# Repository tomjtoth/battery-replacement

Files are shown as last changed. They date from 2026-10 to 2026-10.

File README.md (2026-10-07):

# 3.9V battery replacement

I'd like to replace Li-ion cells from the battery package of mobile devices
with this DC DC converter, which shall step 5V received from any USB port/charger down to 3.9V.

## Conflict with charging via USB port

The devices USB port should not be used for charging after this integration.
Special cables (with unconnected VBUS) should be used when connecting to computers.

## Design choices

At 5V3A - a type-C DFP can provide without active negotiation - the _ideal_ power budget is 15W.
That should translate to about 3.84A at 3.9V.

As a worst case scenario I picked the largest transient as 3.8A and V_IN as 4.5V.
Using the converter's formulas I got 272.6mV sag and 12.7mV soar on the output.

My calculations and links to datasheets can be found
[here](https://docs.google.com/spreadsheets/d/1-LQr6ypT5iOjkNXZSsbeC3mkMsgCNXlFd2zotSDCdQk/edit?usp=sharing).

I'd like to produce this via JLCPCB, so I'm using only their components. All components are imported via JLCImport.
I minimized extended component usage, but I'm happy to pay extra for the 549k resistor, to keep the footprint smaller.

### RT5788B converter

Has 7V absolute maximum input voltage and 100% maximum duty cycle, can provide 4A continuously.
I'm not using the PGOOD leg of the converter to save space.

I found 2 revisions of its datasheet and proceeded with the earlier one where C_OUT = 2 x 22uF (vs 3 x 22uF on the newer revision).
C_IN is 22uF which exceeds the 10uF allowed by USB standard on Upward Facing Ports.

### Y4203 load switch

The 250us soft-start allows the above mentioned 22uF C_IN to be charged.
Has 6.1V OVP with 50ns response time.

## Schematics

I tried arranging the converter's pins similarly to as seen in the datasheet's Typical Application Circuit.

schematics

## PCB

The board is 9 x 25mm sized. The minimum 5 pieces of 100x100mm panels (at JLCPCB) should yield 5x10x4 pieces
(leaving 2x5mm strips on 2 sides for manufacturing holes).
I'm using copper pours for GND on both sides.
I placed vias under the converter in hopes of driving heat to the undivided bottom Cu plane.

F.Cu
B.Cu
No.Cu
3D-top
3D-bottom

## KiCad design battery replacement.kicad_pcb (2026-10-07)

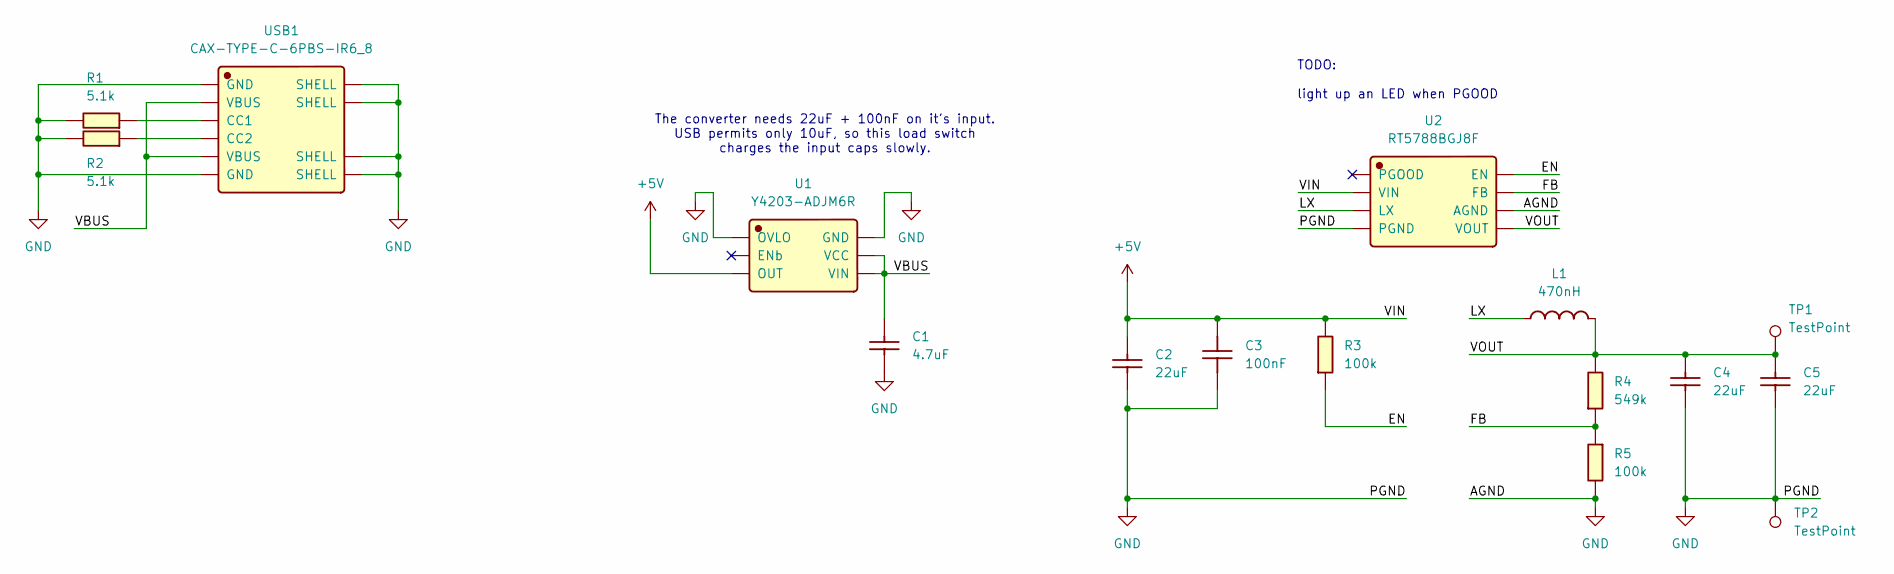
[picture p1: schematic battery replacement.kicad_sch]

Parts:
C1: 4.7uF; CL21A475KAQNNNE; Manufacturer Part CL21A475KAQNNNE; LCSC C1779
C2, C4, C5: 22uF; CL31A226KAHNNNE; Manufacturer Part CL31A226KAHNNNE; LCSC C12891
C3: 100nF; CL05B104KB54PNC; Manufacturer Part CL05B104KB54PNC; LCSC C307331
L1: 470nH; TMS252012ALM-R47MTAA; Manufacturer Part TMS252012ALM-R47MTAA; LCSC C24296304
R1, R2: 5.1k; 0402WGF5101TCE; Manufacturer Part 0402WGF5101TCE; LCSC C25905
R3, R5: 100k; 0402WGF1003TCE; Manufacturer Part 0402WGF1003TCE; LCSC C25741
R4: 549k; 0402WGF5493TCE; Manufacturer Part 0402WGF5493TCE; LCSC C25795
TP1, TP2: TestPoint; TestPoint_THTPad_D1.0mm_Drill0.5mm
U1: Y4203-ADJM6R; Manufacturer Part Y4203-ADJM6R; LCSC C49270370
U2: RT5788BGJ8F; Manufacturer Part RT5788BGJ8F; LCSC C3194337
USB1: CAX-TYPE-C-6PBS-IR6_8; Manufacturer Part CAX-TYPE-C-6PBS-IR6.8; LCSC C55072612

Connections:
+5V: C2.2, C3.1, R3.2, U1.3 (OUT), U2.2 (VIN)
/EN: R3.1, U2.8 (EN)
/FB: R4.1, R5.1, U2.7 (FB)
/LX: L1.1, U2.3 (LX)
/VBUS: C1.2, U1.4 (VIN), U1.5 (VCC), USB1.A9 (VBUS), USB1.B9 (VBUS)
/VOUT: C4.2, C5.2, L1.2, R4.2, TP1.1 (1_1), U2.5 (VOUT)
GND: C1.1, C2.1, C3.2, C4.1, C5.1, R1.2, R2.2, R5.2, TP2.1 (1_1), U1.1 (OVLO), U1.6 (GND), U2.4 (PGND), U2.6 (AGND), USB1.1 (SHELL), USB1.2 (SHELL), USB1.3 (SHELL), USB1.4 (SHELL), USB1.A12 (GND), USB1.B12 (GND)
unnamed: R1.1, USB1.A5 (CC1)
unnamed: R2.1, USB1.B5 (CC2)

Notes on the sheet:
TODO: light up an LED when PGOOD
The converter needs 22uF + 100nF on it's input. USB permits only 10uF, so this load switch charges the input caps slowly.

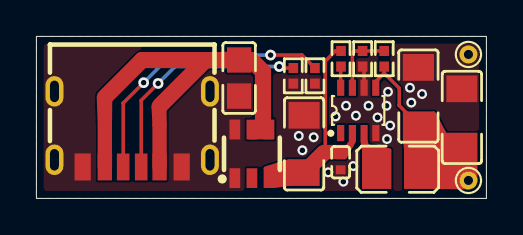
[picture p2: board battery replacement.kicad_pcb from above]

Board: 2 copper layers, 25.0 x 9.0 mm, 16 parts (0 on the bottom side), 9 nets.

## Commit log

2026-09-26 11.1 x 22.5mm
    [battery replacement.kicad_pcb, battery replacement.kicad_sch]
2026-10-01 prelim. 10x25mm ~ 180pcs
    [battery replacement.kicad_pcb, battery replacement.kicad_sch]
2026-10-01 prelim 9x25mm ~ 200pcs
    [battery replacement.kicad_pcb, battery replacement.kicad_sch]
2026-10-07 added load switch datasheet
2026-10-07 kicad prelim version
    [battery replacement.kicad_pcb, battery replacement.kicad_sch]
